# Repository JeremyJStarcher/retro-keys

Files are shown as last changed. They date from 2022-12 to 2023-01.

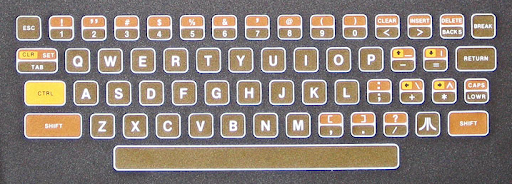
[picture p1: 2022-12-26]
keyboards/atari-a8/img/atari-400-keyboard-layout.png

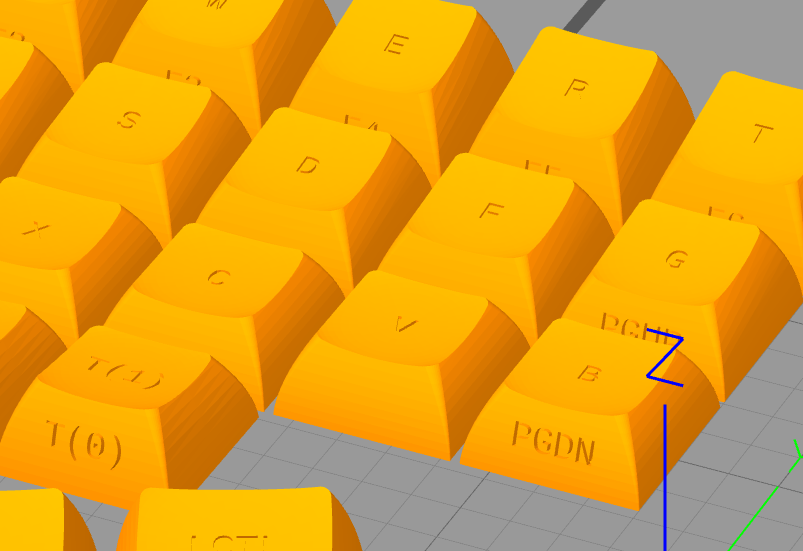
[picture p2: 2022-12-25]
keyboards/openscad/KeyV2/assets/dual_legends.png

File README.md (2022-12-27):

# retro-keys

Retro Keyboards for Emulators

## Purpose

The purpose of this project is to set up a tools to make it easier to create
a custom keyboard to use retro-style computers on modern emulators.

This includes the PCB, keycaps and (in time) a case.

Better integration with [QMK](https://qmk.fm/) is planned.

## Keyboard support

* Atari 800/800XL style keyboard.

## Requirements

* Python 3.10
* OpenSCAD
* KiCad
* VcCode (other editors will work but may require configuration)

## After clone

All of the Python scripts run in a `virtual environment` which will allow them to
access privately installed libraries.

### Step 1 - Install Python `venv`

This package must be installed globally.

    pip install venv

### Step 2 - Create the virtual environment (only needs done once after clone)

In your shell/commandline of choice, change directory to the project root `py`
directory.

    python3 -m venv .venv

### Step 3 - Enter virtual environment (needs done every time you with with `retro-keys`)

From the `py` directory, enter the following command

Linux/Unix:

    source .venv/bin/activate

### Step 4 - Install the required libraries into the virtual environment.

    ./py_libs.sh

## Directory layout

The `keyboards` directory contains the data required for each unique keyboard
as well as common code (and graphics) libraries that are used by all keyboards.

    * `atari-a8` - Keyboard 800/800XL layout
    * `c64-vic20` - C64/VIC20 keyboard (in development)
    * `kicad-lib` - Graphics libraries
    * `openscad` - Open SCAD libraries
    * `retrologo-kb` - Fake keyboard used to generate website graphics.

For each actual keyboard, the directory structure is:

    * `kicad` - The KiCad project for that keyboard
    * `keycaps` - The OpenSCAD scripts to generate the keyboard.

It is important to note that the generated key graphics, stl and wrl files are NOT
checked into the repo as they would take up a large amount of space and must be
regenerated when working on that keyboard.

### Working with an existing keyboard

Yet to be documented.  This workflow is still somewhat reliant on a QMK script
outside the `retro-keys` project directory structure.

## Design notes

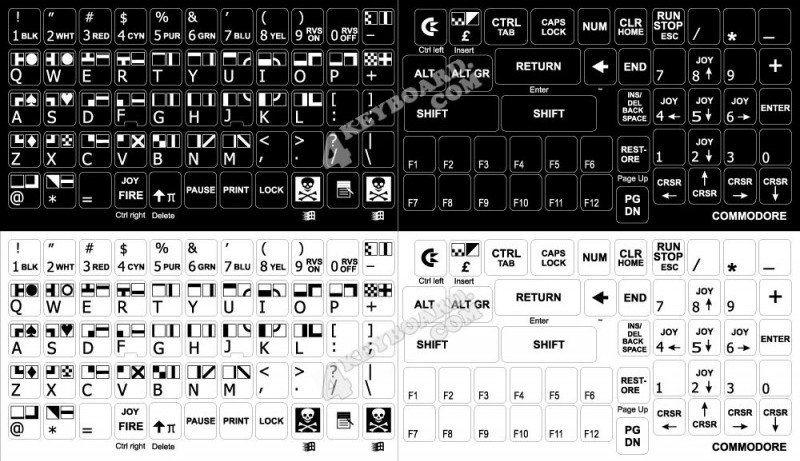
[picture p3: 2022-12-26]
keyboards/c64-vic20/imgs/4kb-c64_stickers.jpg

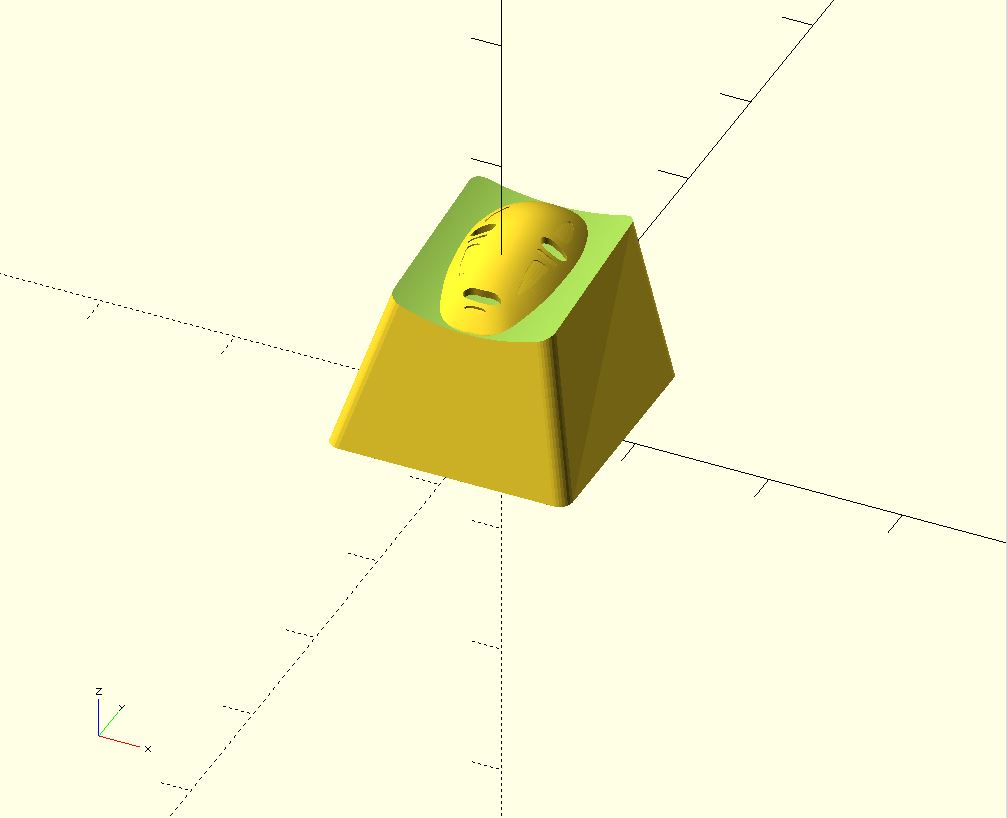
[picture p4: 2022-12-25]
keyboards/openscad/KeyV2/assets/example4.JPG

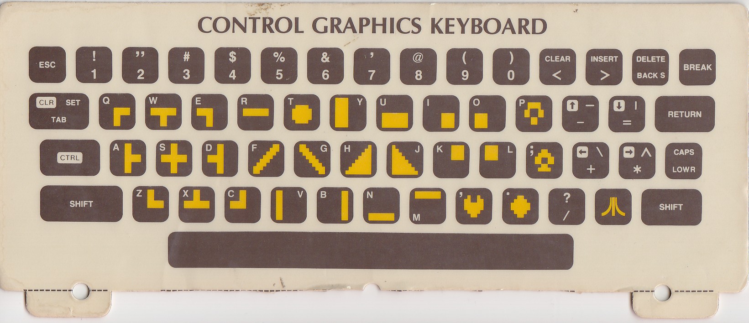
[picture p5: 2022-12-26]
keyboards/atari-a8/img/atari-keyboard-graphics.jpg

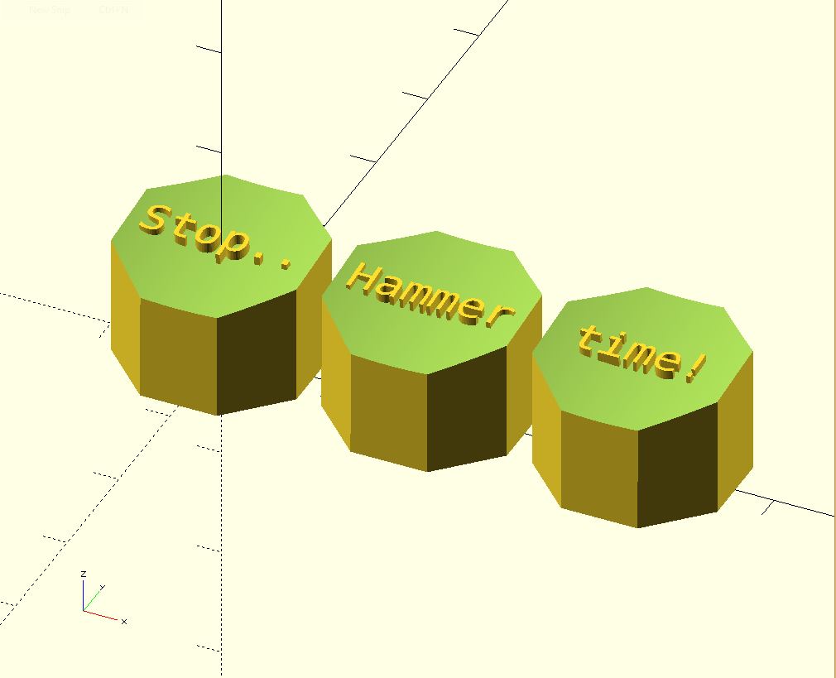
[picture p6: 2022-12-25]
keyboards/openscad/KeyV2/assets/example5.JPG

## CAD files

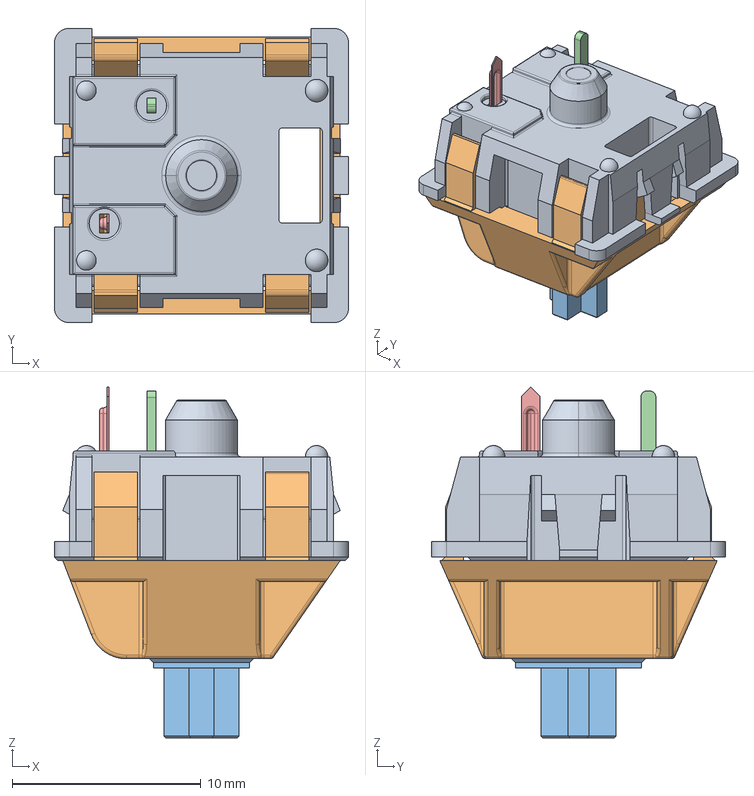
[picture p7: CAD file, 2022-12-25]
keyboards/kicad-lib/3d-models/cherry-mx-switches/asm_mx_asm_PLATE.stp
15.6 x 15.6 x 18.6 mm
MX_DOWN
MX_UP
UP_MX
MX_PIN
MX_SPRING
MX_CLICK

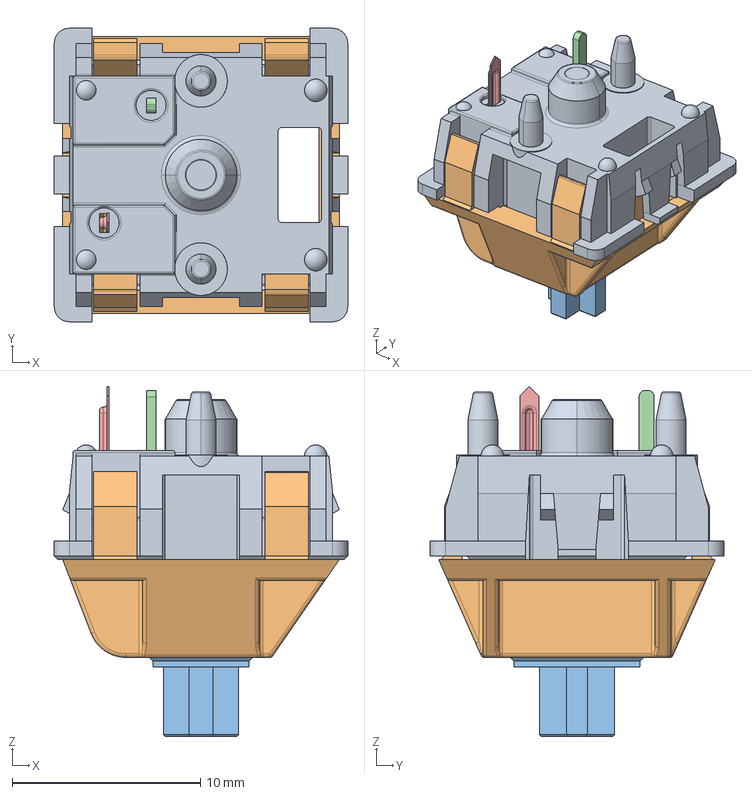
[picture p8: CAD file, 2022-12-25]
keyboards/kicad-lib/3d-models/cherry-mx-switches/asm_mx_asm_PCB.stp
15.6 x 15.6 x 18.6 mm
MX_DOWN
MX_UP
UP_MX
MX_PIN
MX_SPRING
MX_CLICK

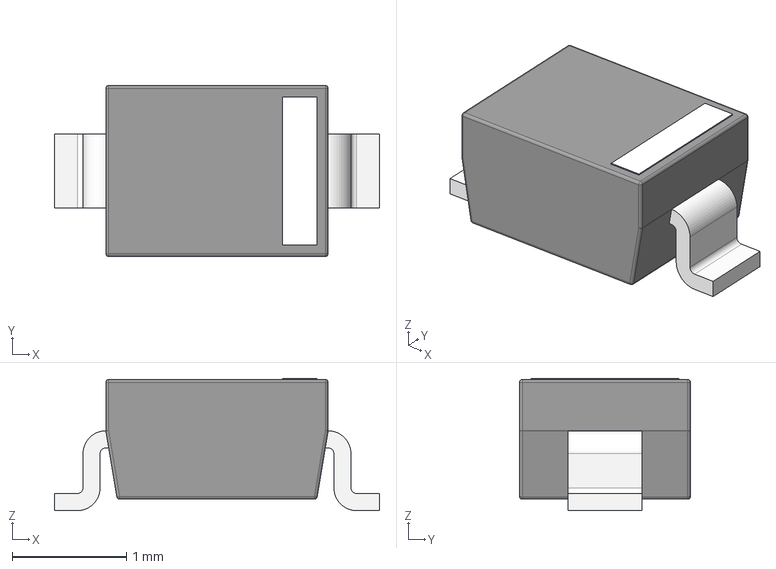
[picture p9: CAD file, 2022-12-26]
keyboards/kicad-lib/3d-models/SOD-diodes/SOD-323.step
2.85 x 1.50 x 1.16 mm

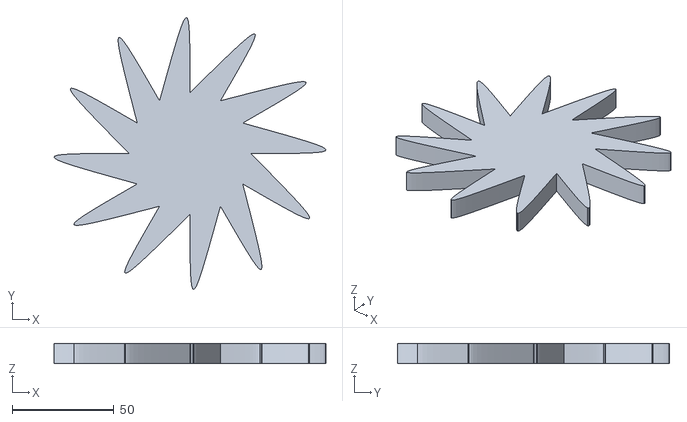
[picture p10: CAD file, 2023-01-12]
keyboards/openscad/josl/josl/bezier/examples/flower.stl
134.0 x 134.0 x 10.0

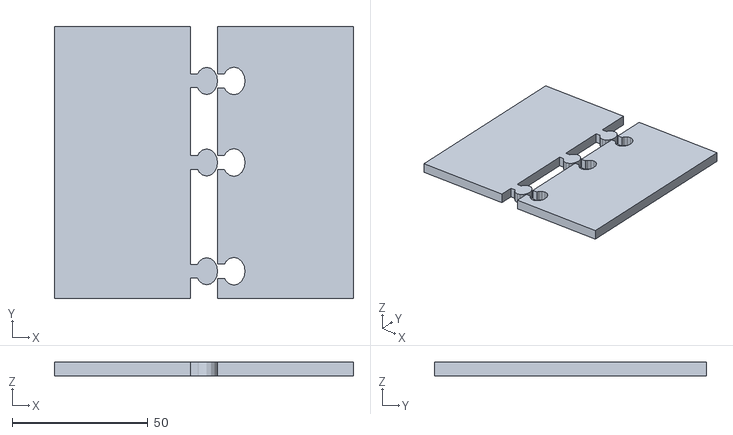
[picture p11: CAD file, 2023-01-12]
keyboards/openscad/josl/josl/cuts/examples/box-example.stl
110.0 x 100.0 x 5.00

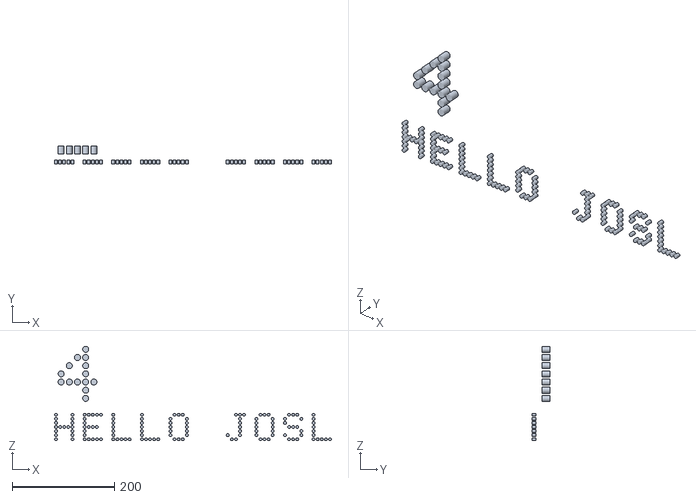
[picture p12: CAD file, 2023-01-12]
keyboards/openscad/josl/josl/dotletter/examples/hello-josl.stl
542.0 x 36.0 x 184.8

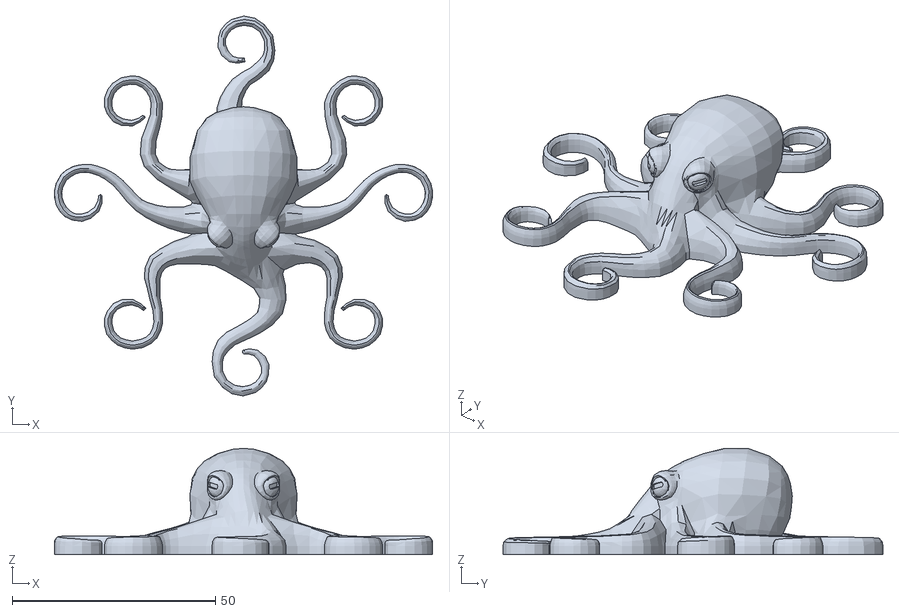
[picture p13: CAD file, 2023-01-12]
keyboards/openscad/puzzlecut/files/OctopusThickLegs.stl
93.0 x 93.4 x 26.1

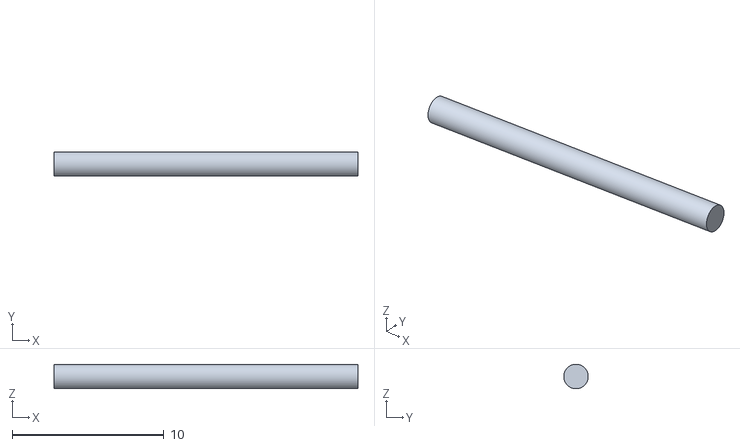
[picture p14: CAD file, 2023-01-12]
keyboards/openscad/test.stl
20.0 x 1.61 x 1.61

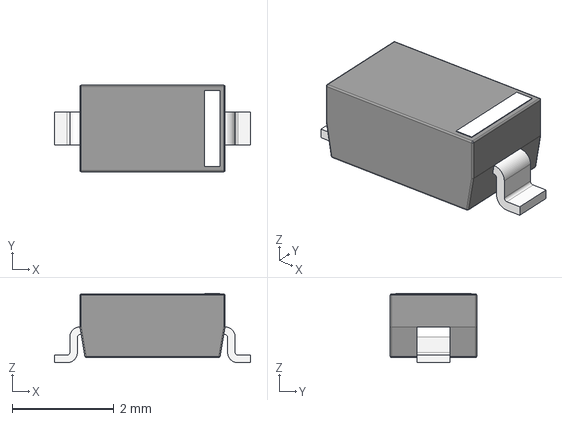
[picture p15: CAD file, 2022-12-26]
keyboards/kicad-lib/3d-models/SOD-diodes/SOD-123.step
3.85 x 1.70 x 1.36 mm

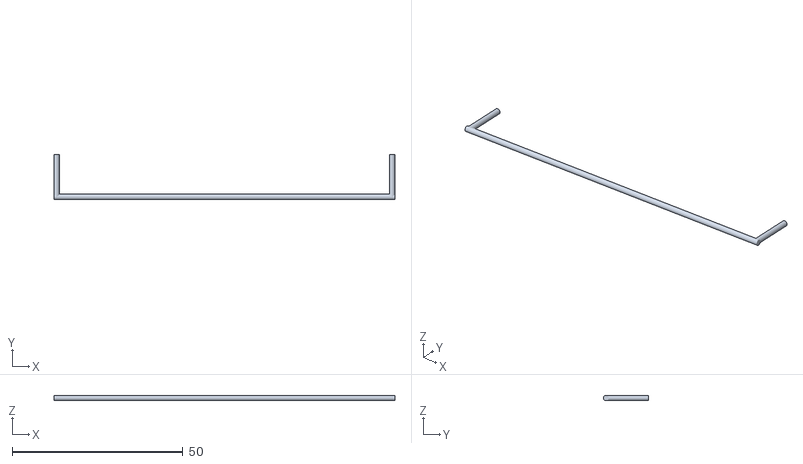
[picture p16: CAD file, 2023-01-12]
keyboards/openscad/625u.stl
100.0 x 13.3 x 1.61

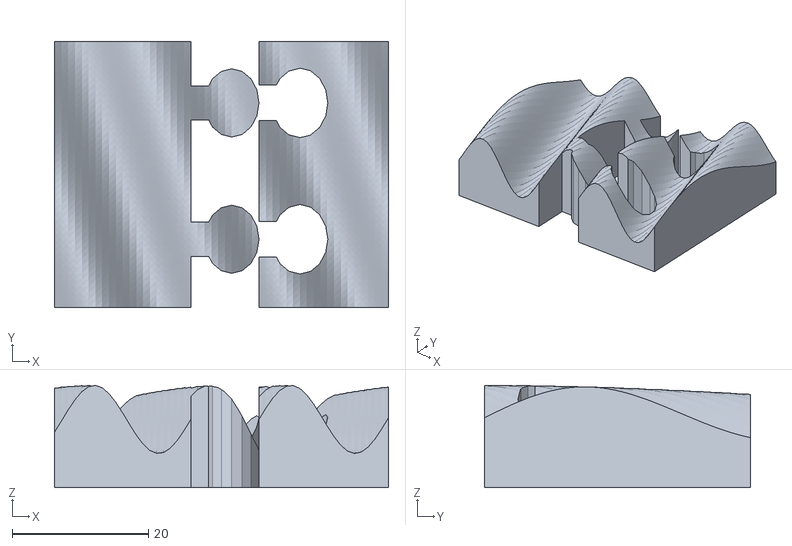
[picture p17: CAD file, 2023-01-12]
keyboards/openscad/josl/josl/cuts/examples/surface-example.stl
49.0 x 39.0 x 15.0

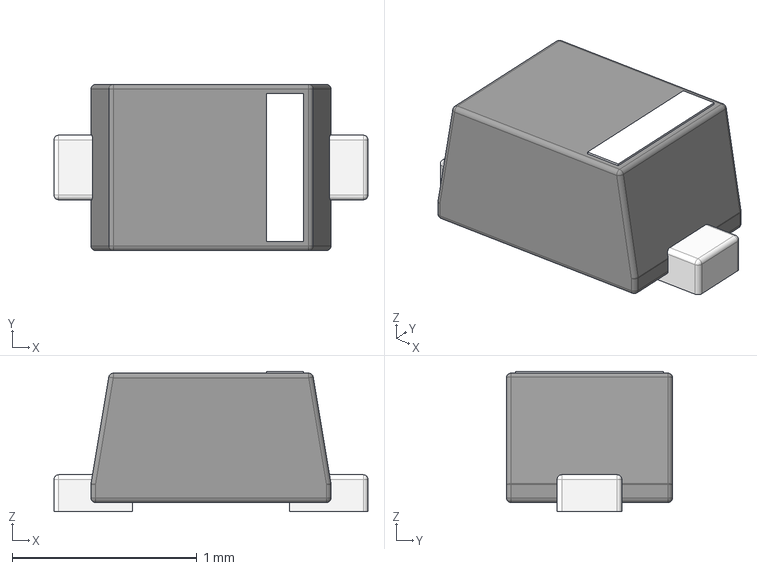
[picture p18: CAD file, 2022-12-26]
keyboards/kicad-lib/3d-models/SOD-diodes/SOD-523.step
1.70 x 0.9 x 0.76 mm

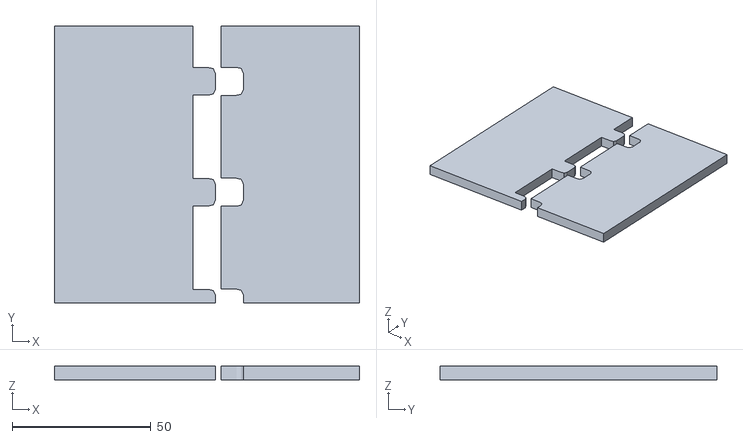
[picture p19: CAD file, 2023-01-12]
keyboards/openscad/josl/josl/cuts/examples/rounded-box-example.stl
110.0 x 100.0 x 5.00

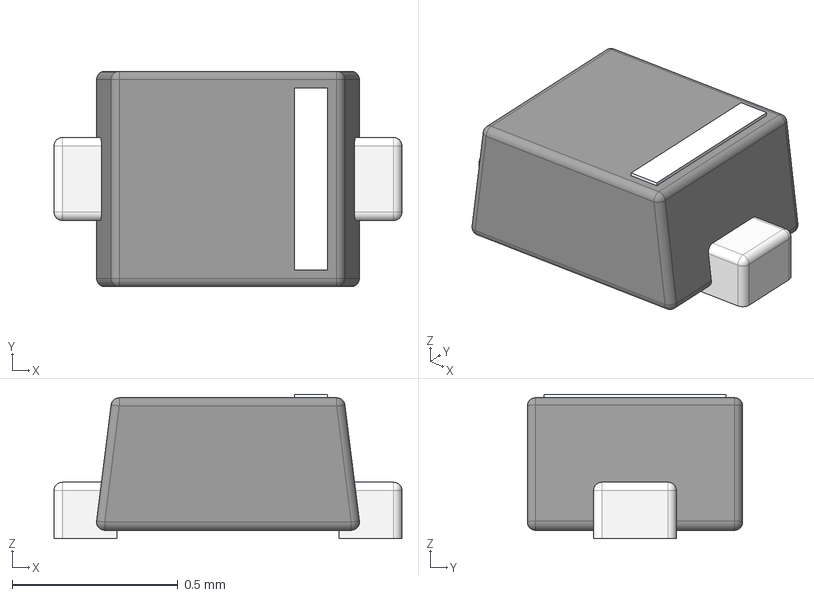
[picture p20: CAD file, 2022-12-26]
keyboards/kicad-lib/3d-models/SOD-diodes/SOD-923 0.2mm Lead Width.step
1.05 x 0.65 x 0.435 mm

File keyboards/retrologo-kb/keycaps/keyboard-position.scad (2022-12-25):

KEY_ESC = [0, 1.5, 63.38125, 206.325];
KEY_1 = [1.25, 1.5, 84.8125, 206.325];
KEY_2 = [2.25, 1.5, 103.86250000000001, 206.325];
KEY_3 = [3.25, 1.5, 122.9125, 206.325];
KEY_4 = [4.25, 1.5, 141.9625, 206.325];
KEY_5 = [5.25, 1.5, 161.0125, 206.325];
KEY_6 = [6.25, 1.5, 180.0625, 206.325];
KEY_7 = [7.25, 1.5, 199.1125, 206.325];
KEY_8 = [8.25, 1.5, 218.1625, 206.325];
KEY_9 = [9.25, 1.5, 237.2125, 206.325];
KEY_0 = [10.25, 1.5, 256.26250000000005, 206.325];
KEY_LT = [11.25, 1.5, 275.3125, 206.325];
KEY_GT = [12.25, 1.5, 294.3625, 206.325];
KEY_BS = [13.25, 1.5, 322.9375, 206.325];
KEY_C_UP = [14.25, 4.5, 332.46250000000003, 263.475];
KEY_C_LEFT = [13.25, 5.5, 313.4125, 282.525];
KEY_C_DOWN = [14.25, 5.5, 332.46250000000003, 282.525];
KEY_C_RIGHT = [15.25, 5.5, 351.5125, 282.525];
KEY_TAB = [0, 2.5, 68.14375, 225.375];
KEY_Q = [1.75, 2.5, 94.3375, 225.375];
KEY_W = [2.75, 2.5, 113.3875, 225.375];
KEY_E = [3.75, 2.5, 132.4375, 225.375];
KEY_R = [4.75, 2.5, 151.4875, 225.375];
KEY_T = [5.75, 2.5, 170.53750000000002, 225.375];
KEY_Y = [6.75, 2.5, 189.5875, 225.375];
KEY_U = [7.75, 2.5, 208.63750000000002, 225.375];
KEY_I = [8.75, 2.5, 227.6875, 225.375];
KEY_O = [9.75, 2.5, 246.7375, 225.375];
KEY_P = [10.75, 2.5, 265.7875, 225.375];
KEY_DASH = [11.75, 2.5, 284.8375, 225.375];
KEY_EQUAL = [12.75, 2.5, 303.88750000000005, 225.375];
KEY_RETURN = [13.75, 2.5, 327.7, 225.375];
KEY_HELP = [16.5, 0, 377.70625, 180.13125];
KEY_RESET = [16.5, 1.5, 377.70625, 208.70624999999998];
KEY_OPTION = [16.5, 2.75, 377.70625, 232.51874999999998];
KEY_SELECT = [16.5, 4, 377.70625, 256.33125];
KEY_CONTROL = [0, 3.5, 70.525, 244.425];
KEY_A = [2, 3.5, 99.1, 244.425];
KEY_S = [3, 3.5, 118.15, 244.425];
KEY_D = [4, 3.5, 137.2, 244.425];
KEY_F = [5, 3.5, 156.25, 244.425];
KEY_G = [6, 3.5, 175.3, 244.425];
KEY_H = [7, 3.5, 194.35, 244.425];
KEY_J = [8, 3.5, 213.4, 244.425];
KEY_K = [9, 3.5, 232.45000000000002, 244.425];
KEY_L = [10, 3.5, 251.5, 244.425];
KEY_SEMI = [11, 3.5, 270.55, 244.425];
KEY_PLUS = [12, 3.5, 289.6, 244.425];
KEY_ASTRIX = [13, 3.5, 308.65, 244.425];
KEY_CAPS = [14, 3.5, 330.08125, 244.425];
KEY_START = [16.5, 5.25, 377.70625, 280.14375];
KEY_POWER = [3.25, 0, 125.29374999999999, 180.13125];
KEY_MENU = [5.25, 0, 163.39374999999998, 180.13125];
KEY_TURBO = [6.5, 0, 187.20624999999998, 180.13125];
KEY_FN = [2, 5.5, 99.1, 282.525];
KEY_LSHIFT = [0.25, 4.5, 77.66875, 263.475];
KEY_Z = [2.5, 4.5, 108.625, 263.475];
KEY_X = [3.5, 4.5, 127.675, 263.475];
KEY_C = [4.5, 4.5, 146.72500000000002, 263.475];
KEY_V = [5.5, 4.5, 165.775, 263.475];
KEY_B = [6.5, 4.5, 184.825, 263.475];
KEY_N = [7.5, 4.5, 203.875, 263.475];
KEY_M = [8.5, 4.5, 222.925, 263.475];
KEY_COMMA = [9.5, 4.5, 241.975, 263.475];
KEY_PERIOD = [10.5, 4.5, 261.025, 263.475];
KEY_SLASH = [11.5, 4.5, 280.07500000000005, 263.475];
KEY_RSHIFT = [12.5, 4.5, 306.26875, 263.475];
KEY_INV = [12.75, 0, 306.26875000000007, 180.13125];
KEY_BREAK = [14, 0, 330.08125, 180.13125];
KEY_SPACE = [4.75, 5.5, 201.49375, 282.525];

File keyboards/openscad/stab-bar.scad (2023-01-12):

len = 20; // 100;
deep = 12.5;
d = 1.61; // 1/16"
turn_radius = 2;

$fn = 100;

module outline() {
    module e() {
        translate([len/2 - d/2, deep/2, 0])
        rotate([90, 0, 0])
        cylinder(h = deep, r = d/2, center=true);
    }


     translate([0, 0, 0]) {
        rotate([0, 90, 0])
        cylinder(h = len, r = d/2, center=true);


        
        // e();
        // mirror([1, 0, 0]) e();
    }
}


outline();



module side() {

    
    translate([len/2 - turn_radius, turn_radius/2, 0])

    rotate([0, 0, 90 * 3])
    rotate_extrude( angle=90)
    translate([turn_radius/2,0,0])
    circle(r = d/4);
    
    
    color("blue")
    translate([len/2 - d/2, deep, 0])
    rotate([90, 0, 0])
    cylinder(h = deep - turn_radius/2, r = d/2);
    
}

//rotate([0, 90, 0])
//cylinder(h = len - turn_radius, r = d/2, center=true);

//side();
///mirror([1, 0, 0]) side();

//square([2,10], center=true);

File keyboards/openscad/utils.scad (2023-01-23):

use <./josl/josl/cuts/comb.scad>
use <./josl/josl/cuts/leftright.scad>
use <./josl/josl/cuts/puzzle.scad>
use <./josl/josl/cuts/zigzag.scad>

module main(BOARD_WIDTH, BOARD_LEN, CASE_PIECES, CASE_PIECE)
{
    $fs = 0.5;
    $fa = 5;

    // Radius of the case corner
    CASE_CORNER_R = 3;
    PCB_THICKNESS = 1.6;
    SCREW_HEAD_GAP = 3;
    SCREW_HEAD_R = 3;
    LAYER_HEIGHT = 0.2;

    // HOw much of a gap between the PCB and the case
    CASE_GAP = 2;

    function puzzleApart() = max(BOARD_WIDTH, BOARD_LEN);

    module centerChildren()
    {
        translate([ BOARD_X1, BOARD_Y1, 0 ]) children();
    }

    module tube(or, ir, h)
    {
        difference()
        {
            cylinder(h = h, r = or);
            translate([ 0, 0, -h / 2 ]) cylinder(h = h * 2, r = ir);
        }
    }

    module mirror4()
    {
        children();
        mirror([ 1, 0, 0 ]) children();
        mirror([ 0, 1, 0 ]) children();
        mirror([ 0, 1, 0 ]) mirror([ 1, 0, 0 ]) children();
    }

    module bottomCase(blen2, bwidth2, offset, height)
    {
        blen = blen2 + offset * 2;
        bwidth = bwidth2 + offset * 2;

        hull() mirror4()
        {
            translate([ -blen / 2, -bwidth / 2, 0 ]) cylinder(h = height, r = CASE_CORNER_R);
        }
    }

    module mountingHoles(blen, bwidth, offset, height)
    {
        mirror4()                                                      //
            translate([ -blen / 2 + offset, -bwidth / 2 + offset, 0 ]) //
            cylinder(h = height * 10, r = MOUNTING_HOLE_D / 2);

        // Drop down below the zero line to make sure there is no interference
        mirror4() //
            translate([ -blen / 2 + offset, -bwidth / 2 + offset, -SCREW_HEAD_GAP ])
        { //
            cylinder(h = SCREW_HEAD_GAP * 2, r = SCREW_HEAD_R + 1);
            //  cylinder(h = SCREW_HEAD_GAP *2, r2 = SCREW_HEAD_R+1, r1=MOUNTING_HOLE_D / 2);
        }
    }

    module mountingStandoffs(blen, bwidth, offset, d, height)
    {
        // The real radius gets put in during voids
        color("red") mirror4() translate([ -blen / 2 + offset, -bwidth / 2 + offset, 0 ]) tube(d + 2, .1, height);
    }

    module bodyVoids()
    {
        mountingHoles(BOARD_LEN, BOARD_WIDTH, MOUNTING_HOLE_OFFSET, STANDOFF_HOLE_HEIGHT);
    }

    module line(x1, y1, x2, y2)
    {
        hull()
        {
            translate([
                x1,
                y1,
            ]) cube(2);
            translate([
                x2,
                y2,
            ]) cube(2);
        }
    }

    module standOffs()
    {

        $fa = 1;
        $fs = 1;

        for (standoff = keyStandoffs)
        {
            x = standoff[0];
            y = standoff[1];

            color("black") translate([ x, y, 0 ])
            {
                cylinder(r = STANDOFF_HOLE_OUTER_DIAMETER / 2, h = STANDOFF_HOLE_HEIGHT);
                cylinder(r1 = STANDOFF_HOLE_INNER_DIAMETER / 2, r2 = (STANDOFF_HOLE_INNER_DIAMETER / 2) * .9,
                         h = STANDOFF_HOLE_HEIGHT + PCB_THICKNESS);
            }
        }
    }

    module keyBoundingBoxes()
    {
        for (box = keyBoundingBoxes)
        {
            x1 = box[1];
            y1 = box[2];
            x2 = box[3];
            y2 = box[4];

            translate([ 0, 0, 0 ]) color("blue")
            {
                line(x1, y1, x2, y1);
                line(x1, y2, x2, y2);
                line(x1, y1, x1, y2);
                line(x2, y1, x2, y2);
            }

            cx = (x1 + x2) / 2;
            cy = (y1 + y2) / 2;

            // Grab just the first two characters since the whole name won't fit
            // in a readable font
            char1 = is_string(box[0][0]) ? box[0][0] : "";
            char2 = is_string(box[0][1]) ? box[0][1] : "";
            label = str(char1, char2);

            color("green") translate(v = [ cx, cy, 0 ]) linear_extrude(height = LAYER_HEIGHT)
                text(label, valign = "center", halign = "center", size = 9);
        }
    }

    module centerCubeXy(wid, len, height)
    {
        translate([ -wid / 2, -len / 2, BASE_THICKNESS ]) cube([ wid, len, height ]);
    }

    module body()
    {
        outside_len = BOARD_LEN + CASE_CORNER_R + CASE_GAP;
        outside_width = BOARD_WIDTH + CASE_CORNER_R + CASE_GAP;

        lip_len = outside_len - (CASE_CORNER_R);
        lip_width = outside_width - (CASE_CORNER_R);

        difference()
        {
            union()
            {
                color("cyan") bottomCase(outside_len, outside_width, 0, CASE_HEIGHT);
                translate([ 0, 0, BASE_THICKNESS ]) color("green")
                    bottomCase(lip_len, lip_width, 0, CASE_HEIGHT + 5 - BASE_THICKNESS);
            }

            translate([ 0, 0, -BASE_THICKNESS ])
                centerCubeXy(BOARD_LEN + CASE_GAP, BOARD_WIDTH + CASE_GAP, CASE_HEIGHT * 3);
        }

        // Put the bottom of the case in.
        translate([ 0, 0, 0 ]) //
            color("white")     //
            bottomCase(outside_len, outside_width, 0, BASE_THICKNESS);

        translate([ 0, 0, BASE_THICKNESS ]) centerChildren()
        {
            standOffs();
            keyBoundingBoxes();
        }
        translate([ 0, 0, BASE_THICKNESS ])
            mountingStandoffs(BOARD_LEN, BOARD_WIDTH, MOUNTING_HOLE_OFFSET, MOUNTING_HOLE_D, STANDOFF_HOLE_HEIGHT);
    }

    module keyboardCaseBottom()
    {
        difference()
        {
            body();
            bodyVoids();
        }
    }

    module hideyCube(side, len, width)
    {
        ap = puzzleApart();
        cube([ ap, ap, 100 ], center = true);
    }

    module cutIt(side, len, width)
    {
        $CUT_WIDTH = width;
        ap = puzzleApart();

        factor = 4;

        xOffset = +len / factor + ap / 2;
        xOffsetFixed = xOffset * (side == "r" ? 1 : -1);

        intersection()
        {
            translate([ xOffsetFixed, 0, 0 ]) children();
            hideyCube(side, len, width);
        }
    }

    module split()
    {
        slice = 25;
        list1 = [for (i = [-$CUT_WIDTH:slice:$CUT_WIDTH]) i];
        play = 0.1;

        Puzzle(y = list1, apart = puzzleApart(), play = play)
        {
            children();
        }
    }

    function partial(list, start, end) = [for (i = [start:end]) list[i]];

    module main2()
    {
        // keyboardCaseBottom();

        module cutInto4(c1, c2)
        {
            cutIt(c2, BOARD_LEN / 2, BOARD_WIDTH) //
                split()                           //
                cutIt(c1, BOARD_LEN, BOARD_WIDTH) //
                split()                           //
                keyboardCaseBottom();
        }

        module cutInto2(c1)
        {
            cutIt(c1, BOARD_LEN, BOARD_WIDTH) //
                split()                       //
                keyboardCaseBottom();
        }

        if (CASE_PIECES == 2)
        {
            if (CASE_PIECE == 1)
            {
                cutInto2("l");
            }
            if (CASE_PIECE == 2)
            {
                cutInto2("r");
            }
        }

        if (CASE_PIECES == 4)
        {
            if (CASE_PIECE == 1)
            {
                cutInto4("l", "l");
            }

            if (CASE_PIECE == 2)
            {
                cutInto4("l", "r");
            }

            if (CASE_PIECE == 3)
            {
                cutInto4("r", "l");
            }

            if (CASE_PIECE == 4)
            {
                cutInto4("r", "r");
            }
        }
    }

    main2();

    lst = [ 1, 2, 3, 4, 5, 6, 7, 8, 9 ]; // a list of numbers
    lst2 = [ "red", "yellow", "blue" ];  // a list of strings
    lst3 = [ false, true, undef ];       // a list of booleans

    // https://eribuijs.blogspot.com/2017/10/openscad-lists-and-list-manipulation.html

    // echo(partial(lst, 1, 8));
}

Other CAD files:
keyboards/kicad-lib/3d-models/SOD-diodes/SOD-923 0.3mm Lead Width.step
keyboards/atari-a8/case/case-position.scad
keyboards/atari-a8/keycaps/atarikeys.scad
keyboards/atari-a8/keycaps/key_desc.scad
keyboards/atari-a8/keycaps/key_include.scad
keyboards/atari-a8/keycaps/one_atari_key.scad
keyboards/openscad/KeyV2/customizer.scad
keyboards/openscad/KeyV2/customizer_base.scad
keyboards/openscad/KeyV2/examples/legends.scad
keyboards/openscad/KeyV2/examples/multimaterial_key_top.scad
keyboards/openscad/KeyV2/examples/multimaterial_legend.scad
keyboards/openscad/KeyV2/examples/plate_generation.scad
keyboards/openscad/KeyV2/examples/print_keycaps_on_their_side.scad
keyboards/openscad/KeyV2/examples/sa_ergo.scad
keyboards/openscad/KeyV2/examples/single_extruder_multimaterial_legends.scad
keyboards/openscad/KeyV2/includes.scad
keyboards/openscad/KeyV2/key_mold.scad
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

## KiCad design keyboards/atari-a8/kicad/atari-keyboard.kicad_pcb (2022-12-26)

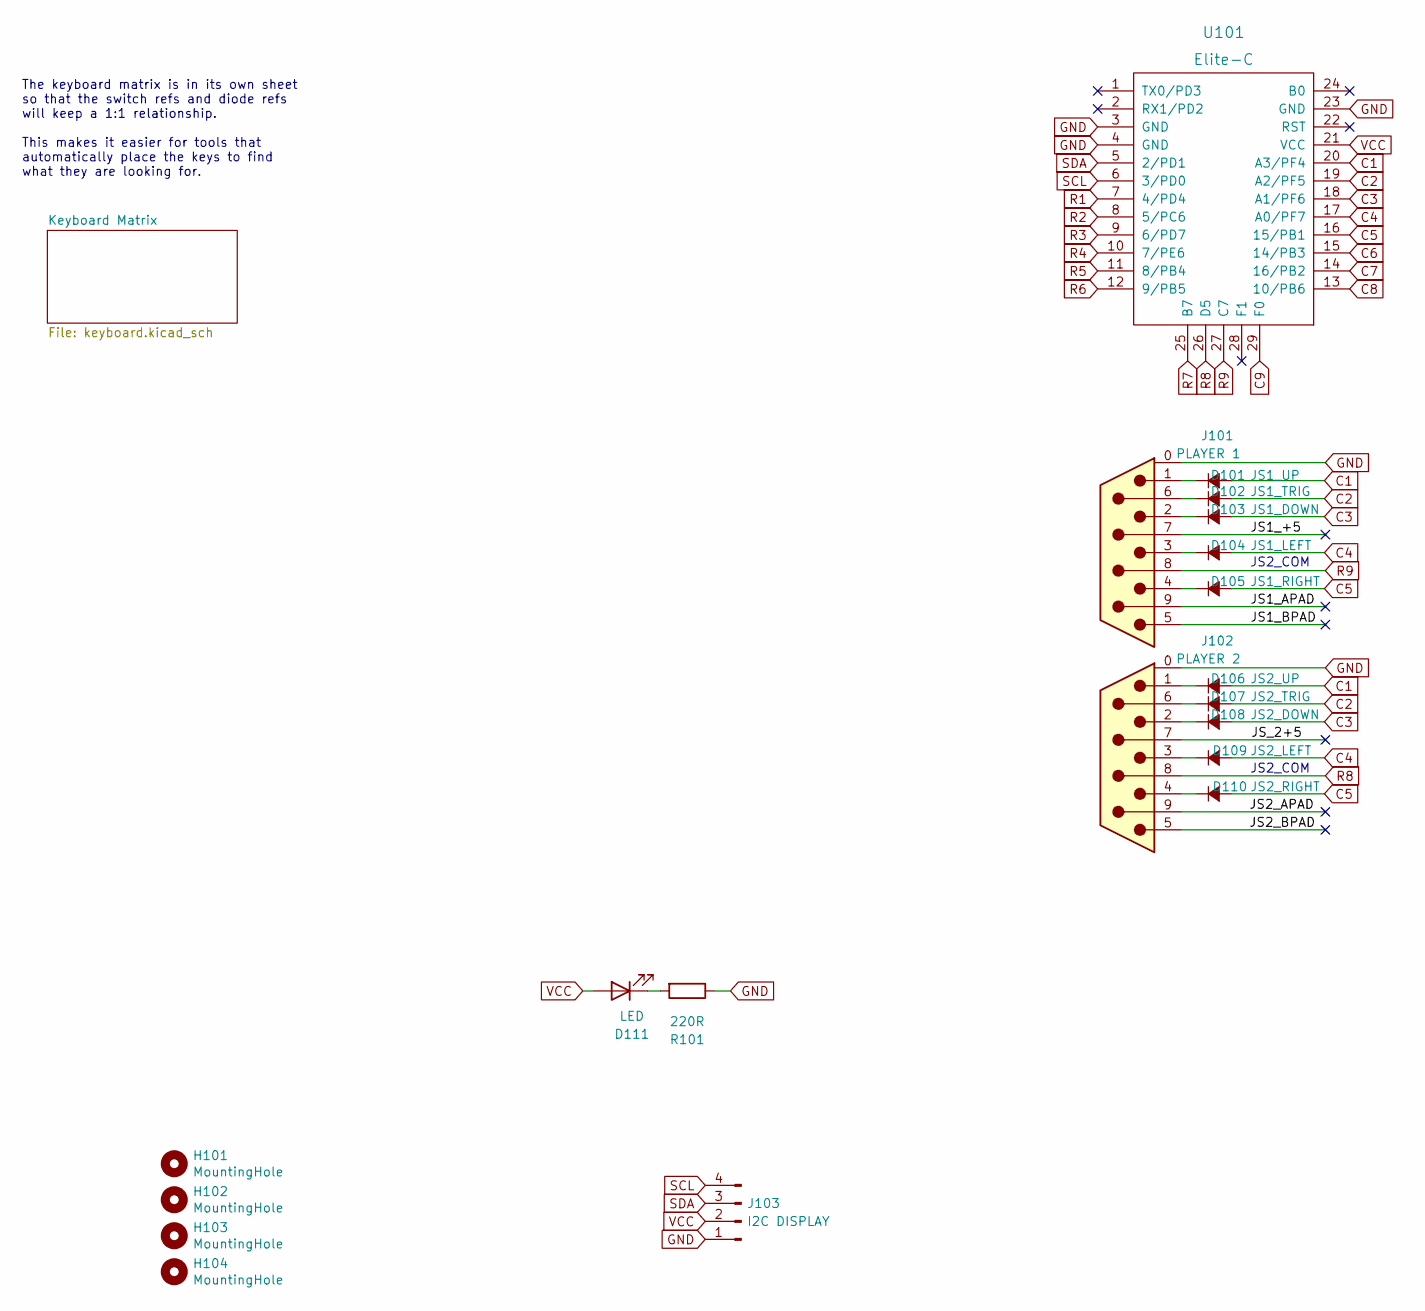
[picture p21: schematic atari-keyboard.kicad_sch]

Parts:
D101: JS1_UP; Diode-dual
D102: JS1_TRIG; Diode-dual
D103: JS1_DOWN; Diode-dual
D104: JS1_LEFT; Diode-dual
D105: JS1_RIGHT; Diode-dual
D106: JS2_UP; Diode-dual
D107: JS2_TRIG; Diode-dual
D108: JS2_DOWN; Diode-dual
D109: JS2_LEFT; Diode-dual
D110: JS2_RIGHT; Diode-dual
D111: LED; LED_D3.0mm
H101, H102, H103, H104: MountingHole; MountingHole_3.2mm_M3
J101: PLAYER 1; DSUB-9_Male_Horizontal_P2.77x2.84mm_EdgePinOffset9.90mm_Hou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
J102: PLAYER 2; DSUB-9_Male_Horizontal_P2.77x2.84mm_EdgePinOffset9.90mm_Hou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
J103: I2C DISPLAY; PinHeader_1x04_P2.54mm_Horizontal
R101: 220R; Resistor-Hybrid
U101: Elite-C; Elite-C-castellated-29pin-holes

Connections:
/JS1_+5: J101.7
/JS1_APAD: J101.9
/JS1_BPAD: J101.5
/JS2_APAD: J102.9
/JS2_BPAD: J102.5
/JS_2+5: J102.7
C1: D101.2 (A), D106.2 (A), U101.20 (A3/PF4); also elsewhere on the board
C2: D102.2 (A), D107.2 (A), U101.19 (A2/PF5); also elsewhere on the board
C3: D103.2 (A), D108.2 (A), U101.18 (A1/PF6); also elsewhere on the board
C4: D104.2 (A), D109.2 (A), U101.17 (A0/PF7); also elsewhere on the board
C5: D105.2 (A), D110.2 (A), U101.16 (15/PB1); also elsewhere on the board
C6: U101.15 (14/PB3); also elsewhere on the board
C7: U101.14 (16/PB2); also elsewhere on the board
C8: U101.13 (10/PB6); also elsewhere on the board
C9: U101.29 (F0); also elsewhere on the board
GND: J101.0 (GND), J102.0 (GND), J103.1, R101.1, U101.3 (GND), U101.4 (GND), U101.23 (GND)
unnamed: D101.1 (K), J101.1
unnamed: D102.1 (K), J101.6
unnamed: D103.1 (K), J101.2
unnamed: D104.1 (K), J101.3
unnamed: D105.1 (K), J101.4
unnamed: D106.1 (K), J102.1
unnamed: D107.1 (K), J102.6
unnamed: D108.1 (K), J102.2
unnamed: D109.1 (K), J102.3
unnamed: D110.1 (K), J102.4
unnamed: D111.1 (K), R101.2
R1: U101.7 (4/PD4); also elsewhere on the board
R2: U101.8 (5/PC6); also elsewhere on the board
R3: U101.9 (6/PD7); also elsewhere on the board
R4: U101.10 (7/PE6); also elsewhere on the board
R5: U101.11 (8/PB4); also elsewhere on the board
R6: U101.12 (9/PB5); also elsewhere on the board
R7: U101.25 (B7); also elsewhere on the board
R8: J102.8, U101.26 (D5); also elsewhere on the board
R9: J101.8, U101.27 (C7); also elsewhere on the board
SCL: J103.4, U101.6 (3/PD0)
SDA: J103.3, U101.5 (2/PD1)
VCC: D111.2 (A), J103.2, U101.21 (VCC)

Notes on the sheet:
JS2_COM
The keyboard matrix is in its own sheet so that the switch refs and diode refs will keep a 1:1 relationship. This makes it easier for tools that automatically place the keys to find what they are looking for.

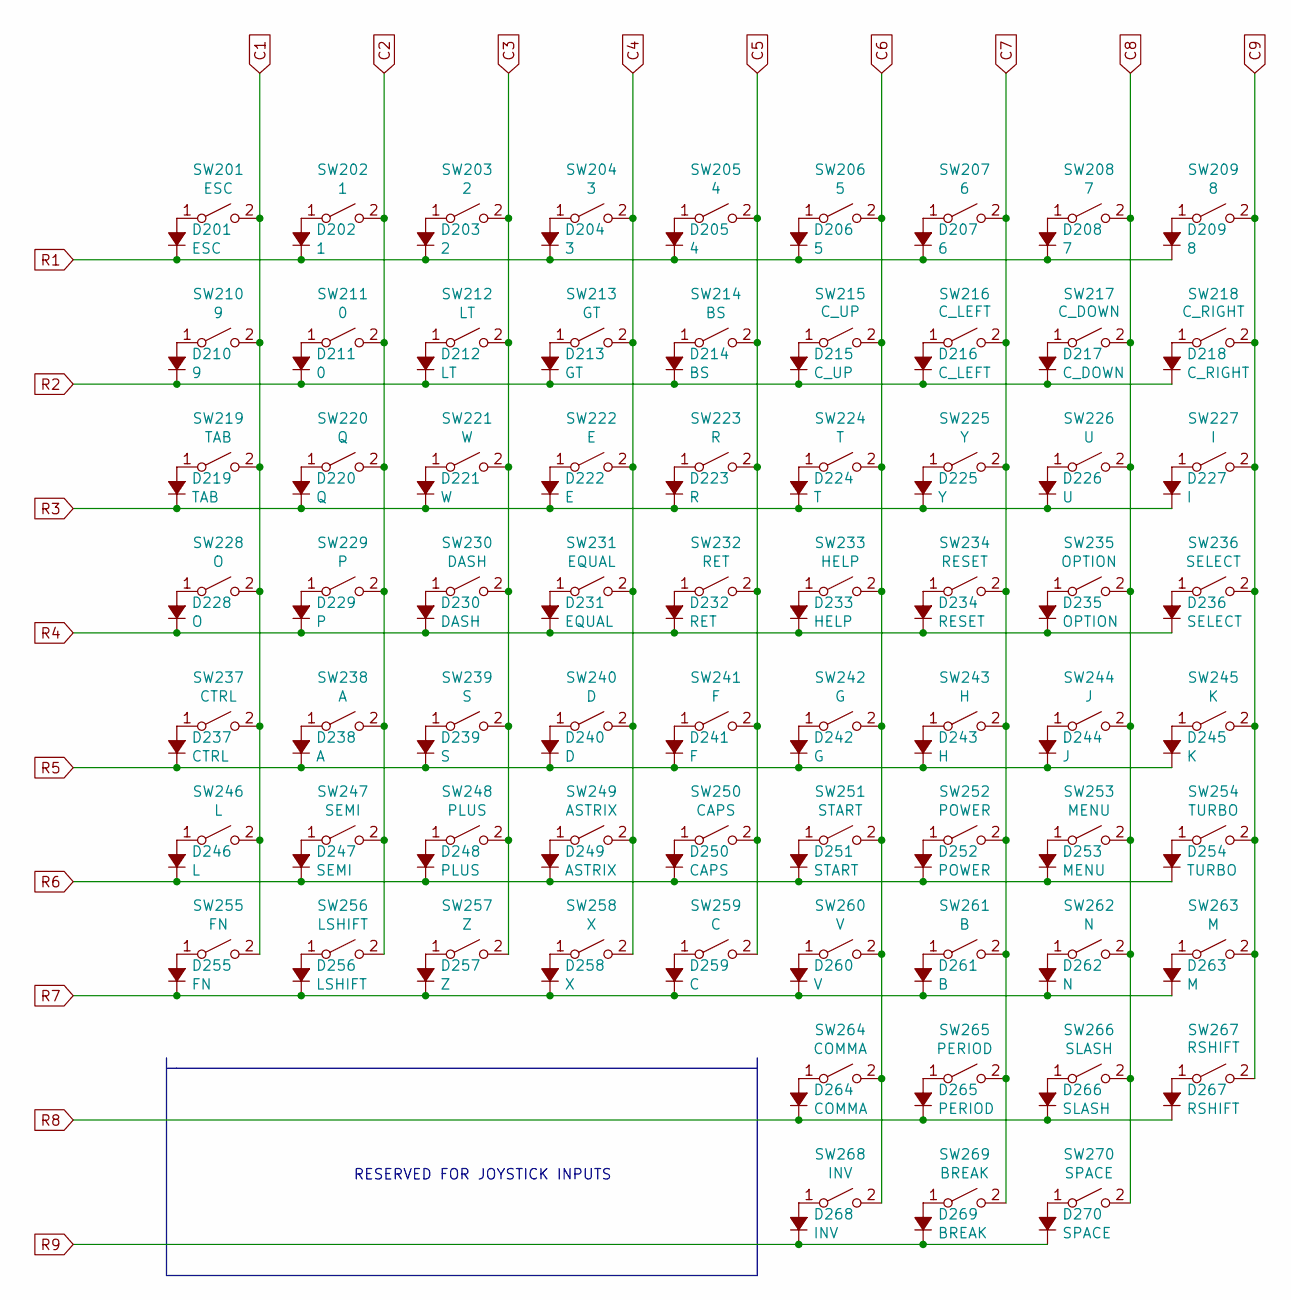
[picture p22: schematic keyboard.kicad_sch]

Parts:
D201: ESC; Diode-dual
D202: 1; Diode-dual
D203: 2; Diode-dual
D204: 3; Diode-dual
D205: 4; Diode-dual
D206: 5; Diode-dual
D207: 6; Diode-dual
D208: 7; Diode-dual
D209: 8; Diode-dual
D210: 9; Diode-dual
D211: 0; Diode-dual
D212: LT; Diode-dual
D213: GT; Diode-dual
D214: BS; Diode-dual
D215: C_UP; Diode-dual
D216: C_LEFT; Diode-dual
D217: C_DOWN; Diode-dual
D218: C_RIGHT; Diode-dual
D219: TAB; Diode-dual
D220: Q; Diode-dual
D221: W; Diode-dual
D222: E; Diode-dual
D223: R; Diode-dual
D224: T; Diode-dual
D225: Y; Diode-dual
D226: U; Diode-dual
D227: I; Diode-dual
D228: O; Diode-dual
D229: P; Diode-dual
D230: DASH; Diode-dual
D231: EQUAL; Diode-dual
D232: RET; Diode-dual
D233: HELP; Diode-dual
D234: RESET; Diode-dual
D235: OPTION; Diode-dual
D236: SELECT; Diode-dual
D237: CTRL; Diode-dual
D238: A; Diode-dual
D239: S; Diode-dual
D240: D; Diode-dual
D241: F; Diode-dual
D242: G; Diode-dual
D243: H; Diode-dual
D244: J; Diode-dual
D245: K; Diode-dual
D246: L; Diode-dual
D247: SEMI; Diode-dual
D248: PLUS; Diode-dual
D249: ASTRIX; Diode-dual
D250: CAPS; Diode-dual
D251: START; Diode-dual
D252: POWER; Diode-dual
D253: MENU; Diode-dual
D254: TURBO; Diode-dual
D255: FN; Diode-dual
D256: LSHIFT; Diode-dual
D257: Z; Diode-dual
D258: X; Diode-dual
D259: C; Diode-dual
D260: V; Diode-dual
D261: B; Diode-dual
D262: N; Diode-dual
D263: M; Diode-dual
D264: COMMA; Diode-dual
D265: PERIOD; Diode-dual
D266: SLASH; Diode-dual
D267: RSHIFT; Diode-dual
D268: INV; Diode-dual
D269: BREAK; Diode-dual
D270: SPACE; Diode-dual
SW201: ESC; SW_Cherry_MX_1.25u_PCB
SW202: 1; SW_Cherry_MX_1.00u_PCB
SW203: 2; SW_Cherry_MX_1.00u_PCB
SW204: 3; SW_Cherry_MX_1.00u_PCB
SW205: 4; SW_Cherry_MX_1.00u_PCB
SW206: 5; SW_Cherry_MX_1.00u_PCB
SW207: 6; SW_Cherry_MX_1.00u_PCB
SW208: 7; SW_Cherry_MX_1.00u_PCB
SW209: 8; SW_Cherry_MX_1.00u_PCB
SW210: 9; SW_Cherry_MX_1.00u_PCB
SW211: 0; SW_Cherry_MX_1.00u_PCB
SW212: LT; SW_Cherry_MX_1.00u_PCB
SW213: GT; SW_Cherry_MX_1.00u_PCB
SW214: BS; SW_Cherry_MX_2.00u_PCB
SW215: C_UP; SW_Cherry_MX_1.00u_PCB
SW216: C_LEFT; SW_Cherry_MX_1.00u_PCB
SW217: C_DOWN; SW_Cherry_MX_1.00u_PCB
SW218: C_RIGHT; SW_Cherry_MX_1.00u_PCB
SW219: TAB; SW_Cherry_MX_1.75u_PCB
SW220: Q; SW_Cherry_MX_1.00u_PCB
SW221: W; SW_Cherry_MX_1.00u_PCB
SW222: E; SW_Cherry_MX_1.00u_PCB
SW223: R; SW_Cherry_MX_1.00u_PCB
SW224: T; SW_Cherry_MX_1.00u_PCB
SW225: Y; SW_Cherry_MX_1.00u_PCB
SW226: U; SW_Cherry_MX_1.00u_PCB
SW227: I; SW_Cherry_MX_1.00u_PCB
SW228: O; SW_Cherry_MX_1.00u_PCB
SW229: P; SW_Cherry_MX_1.00u_PCB
SW230: DASH; SW_Cherry_MX_1.00u_PCB
SW231: EQUAL; SW_Cherry_MX_1.00u_PCB
SW232: RET; SW_Cherry_MX_1.50u_PCB
SW233: HELP; SW_Cherry_MX_1.00u_PCB
SW234: RESET; SW_Cherry_MX_1.00u_PCB
SW235: OPTION; SW_Cherry_MX_1.00u_PCB
SW236: SELECT; SW_Cherry_MX_1.00u_PCB
SW237: CTRL; SW_Cherry_MX_2.00u_PCB
SW238: A; SW_Cherry_MX_1.00u_PCB
SW239: S; SW_Cherry_MX_1.00u_PCB
SW240: D; SW_Cherry_MX_1.00u_PCB
SW241: F; SW_Cherry_MX_1.00u_PCB
SW242: G; SW_Cherry_MX_1.00u_PCB
SW243: H; SW_Cherry_MX_1.00u_PCB
SW244: J; SW_Cherry_MX_1.00u_PCB
SW245: K; SW_Cherry_MX_1.00u_PCB
SW246: L; SW_Cherry_MX_1.00u_PCB
SW247: SEMI; SW_Cherry_MX_1.00u_PCB
SW248: PLUS; SW_Cherry_MX_1.00u_PCB
SW249: ASTRIX; SW_Cherry_MX_1.00u_PCB
SW250: CAPS; SW_Cherry_MX_1.25u_PCB
SW251: START; SW_Cherry_MX_1.00u_PCB
SW252: POWER; SW_Cherry_MX_1.00u_PCB
SW253: MENU; SW_Cherry_MX_1.00u_PCB
SW254: TURBO; SW_Cherry_MX_1.00u_PCB
SW255: FN; SW_Cherry_MX_1.75u_PCB
SW256: LSHIFT; SW_Cherry_MX_2.25u_PCB
SW257: Z; SW_Cherry_MX_1.00u_PCB
SW258: X; SW_Cherry_MX_1.00u_PCB
SW259: C; SW_Cherry_MX_1.00u_PCB
SW260: V; SW_Cherry_MX_1.00u_PCB
SW261: B; SW_Cherry_MX_1.00u_PCB
SW262: N; SW_Cherry_MX_1.00u_PCB
SW263: M; SW_Cherry_MX_1.00u_PCB
SW264: COMMA; SW_Cherry_MX_1.00u_PCB
SW265: PERIOD; SW_Cherry_MX_1.00u_PCB
SW266: SLASH; SW_Cherry_MX_1.00u_PCB
SW267: RSHIFT; SW_Cherry_MX_1.75u_PCB
SW268: INV; SW_Cherry_MX_1.00u_PCB
SW269: BREAK; SW_Cherry_MX_1.00u_PCB
SW270: SPACE; SW_Cherry_MX_6.25u_PCB

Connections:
C1: SW201.2 (B), SW210.2 (B), SW219.2 (B), SW228.2 (B), SW237.2 (B), SW246.2 (B), SW255.2 (B); also elsewhere on the board
C2: SW202.2 (B), SW211.2 (B), SW220.2 (B), SW229.2 (B), SW238.2 (B), SW247.2 (B), SW256.2 (B); also elsewhere on the board
C3: SW203.2 (B), SW212.2 (B), SW221.2 (B), SW230.2 (B), SW239.2 (B), SW248.2 (B), SW257.2 (B); also elsewhere on the board
C4: SW204.2 (B), SW213.2 (B), SW222.2 (B), SW231.2 (B), SW240.2 (B), SW249.2 (B), SW258.2 (B); also elsewhere on the board
C5: SW205.2 (B), SW214.2 (B), SW223.2 (B), SW232.2 (B), SW241.2 (B), SW250.2 (B), SW259.2 (B); also elsewhere on the board
C6: SW206.2 (B), SW215.2 (B), SW224.2 (B), SW233.2 (B), SW242.2 (B), SW251.2 (B), SW260.2 (B), SW264.2 (B), SW268.2 (B); also elsewhere on the board
C7: SW207.2 (B), SW216.2 (B), SW225.2 (B), SW234.2 (B), SW243.2 (B), SW252.2 (B), SW261.2 (B), SW265.2 (B), SW269.2 (B); also elsewhere on the board
C8: SW208.2 (B), SW217.2 (B), SW226.2 (B), SW235.2 (B), SW244.2 (B), SW253.2 (B), SW262.2 (B), SW266.2 (B), SW270.2 (B); also elsewhere on the board
C9: SW209.2 (B), SW218.2 (B), SW227.2 (B), SW236.2 (B), SW245.2 (B), SW254.2 (B), SW263.2 (B), SW267.2 (B); also elsewhere on the board
unnamed: D201.2 (A), SW201.1 (A)
unnamed: D202.2 (A), SW202.1 (A)
unnamed: D203.2 (A), SW203.1 (A)
unnamed: D204.2 (A), SW204.1 (A)
unnamed: D205.2 (A), SW205.1 (A)
unnamed: D206.2 (A), SW206.1 (A)
unnamed: D207.2 (A), SW207.1 (A)
unnamed: D208.2 (A), SW208.1 (A)
unnamed: D209.2 (A), SW209.1 (A)
unnamed: D210.2 (A), SW210.1 (A)
unnamed: D211.2 (A), SW211.1 (A)
unnamed: D212.2 (A), SW212.1 (A)
unnamed: D213.2 (A), SW213.1 (A)
unnamed: D214.2 (A), SW214.1 (A)
unnamed: D215.2 (A), SW215.1 (A)
unnamed: D216.2 (A), SW216.1 (A)
unnamed: D217.2 (A), SW217.1 (A)
unnamed: D218.2 (A), SW218.1 (A)
unnamed: D219.2 (A), SW219.1 (A)
unnamed: D220.2 (A), SW220.1 (A)
unnamed: D221.2 (A), SW221.1 (A)
unnamed: D222.2 (A), SW222.1 (A)
unnamed: D223.2 (A), SW223.1 (A)
unnamed: D224.2 (A), SW224.1 (A)
unnamed: D225.2 (A), SW225.1 (A)
unnamed: D226.2 (A), SW226.1 (A)
unnamed: D227.2 (A), SW227.1 (A)
unnamed: D228.2 (A), SW228.1 (A)
unnamed: D229.2 (A), SW229.1 (A)
unnamed: D230.2 (A), SW230.1 (A)
unnamed: D231.2 (A), SW231.1 (A)
unnamed: D232.2 (A), SW232.1 (A)
unnamed: D233.2 (A), SW233.1 (A)
unnamed: D234.2 (A), SW234.1 (A)
unnamed: D235.2 (A), SW235.1 (A)
unnamed: D236.2 (A), SW236.1 (A)
unnamed: D237.2 (A), SW237.1 (A)
unnamed: D238.2 (A), SW238.1 (A)
unnamed: D239.2 (A), SW239.1 (A)
unnamed: D240.2 (A), SW240.1 (A)
unnamed: D241.2 (A), SW241.1 (A)
unnamed: D242.2 (A), SW242.1 (A)
unnamed: D243.2 (A), SW243.1 (A)
unnamed: D244.2 (A), SW244.1 (A)
unnamed: D245.2 (A), SW245.1 (A)
unnamed: D246.2 (A), SW246.1 (A)
unnamed: D247.2 (A), SW247.1 (A)
unnamed: D248.2 (A), SW248.1 (A)
unnamed: D249.2 (A), SW249.1 (A)
unnamed: D250.2 (A), SW250.1 (A)
unnamed: D251.2 (A), SW251.1 (A)
unnamed: D252.2 (A), SW252.1 (A)
unnamed: D253.2 (A), SW253.1 (A)
unnamed: D254.2 (A), SW254.1 (A)
unnamed: D255.2 (A), SW255.1 (A)
unnamed: D256.2 (A), SW256.1 (A)
unnamed: D257.2 (A), SW257.1 (A)
unnamed: D258.2 (A), SW258.1 (A)
unnamed: D259.2 (A), SW259.1 (A)
unnamed: D260.2 (A), SW260.1 (A)
unnamed: D261.2 (A), SW261.1 (A)
unnamed: D262.2 (A), SW262.1 (A)
unnamed: D263.2 (A), SW263.1 (A)
unnamed: D264.2 (A), SW264.1 (A)
unnamed: D265.2 (A), SW265.1 (A)
unnamed: D266.2 (A), SW266.1 (A)
unnamed: D267.2 (A), SW267.1 (A)
unnamed: D268.2 (A), SW268.1 (A)
unnamed: D269.2 (A), SW269.1 (A)
unnamed: D270.2 (A), SW270.1 (A)
R1: D201.1 (K), D202.1 (K), D203.1 (K), D204.1 (K), D205.1 (K), D206.1 (K), D207.1 (K), D208.1 (K), D209.1 (K); also elsewhere on the board
R2: D210.1 (K), D211.1 (K), D212.1 (K), D213.1 (K), D214.1 (K), D215.1 (K), D216.1 (K), D217.1 (K), D218.1 (K); also elsewhere on the board
R3: D219.1 (K), D220.1 (K), D221.1 (K), D222.1 (K), D223.1 (K), D224.1 (K), D225.1 (K), D226.1 (K), D227.1 (K); also elsewhere on the board
R4: D228.1 (K), D229.1 (K), D230.1 (K), D231.1 (K), D232.1 (K), D233.1 (K), D234.1 (K), D235.1 (K), D236.1 (K); also elsewhere on the board
R5: D237.1 (K), D238.1 (K), D239.1 (K), D240.1 (K), D241.1 (K), D242.1 (K), D243.1 (K), D244.1 (K), D245.1 (K); also elsewhere on the board
R6: D246.1 (K), D247.1 (K), D248.1 (K), D249.1 (K), D250.1 (K), D251.1 (K), D252.1 (K), D253.1 (K), D254.1 (K); also elsewhere on the board
R7: D255.1 (K), D256.1 (K), D257.1 (K), D258.1 (K), D259.1 (K), D260.1 (K), D261.1 (K), D262.1 (K), D263.1 (K); also elsewhere on the board
R8: D264.1 (K), D265.1 (K), D266.1 (K), D267.1 (K); also elsewhere on the board
R9: D268.1 (K), D269.1 (K), D270.1 (K); also elsewhere on the board

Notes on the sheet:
RESERVED FOR JOYSTICK INPUTS

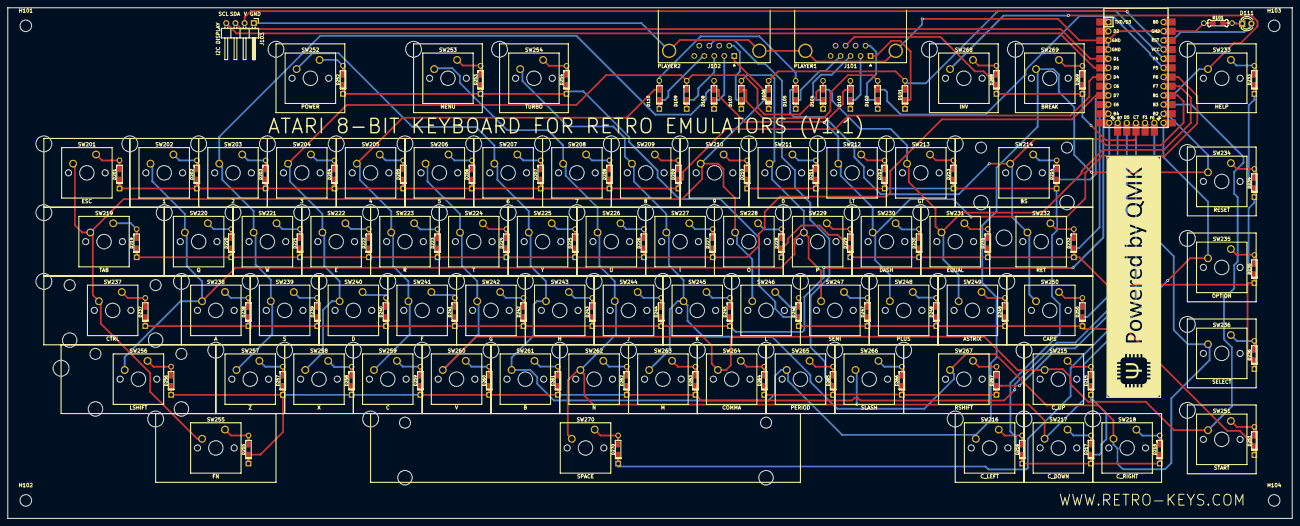
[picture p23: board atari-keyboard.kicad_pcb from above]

Board: 2 copper layers, 355.8 x 141.4 mm, 160 parts (0 on the bottom side), 103 nets.

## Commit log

2022-12-25 Added keycap generator
    [3d_surface.scad, 4x6.scad, 4x6_legends.scad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]
2022-12-25 Added kicad-lib
    [asm_mx_asm_PCB.stp, asm_mx_asm_PLATE.stp]
2022-12-25 Added Atari-A8 PCB
    [atari-keyboard.kicad_sch, atari-keyboard.sch, keyboard.kicad_sch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]
2022-12-26 More cleanup of the PCB traces.
    [router.dsn]
2022-12-26 Added SOD-123 diode models to PCB
    [SOD-123.step, SOD-323.step, SOD-523.step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]
2022-12-26 Replaced unix command line tools to convert stl to wrl with a python script.
2022-12-26 Cleaned up some more trace.
    [atari-keyboard.kicad_pcb]
2022-12-26 No longer need standoff holes as part of the schematic. Added automatically by the script.
2022-12-26 Used new standoff holes and more track cleanup work.
    [atari-keyboard.kicad_pcb, atari-keyboard.kicad_sch, keyboard.kicad_sch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]
2022-12-26 Moved KeyV2 to be used commonly
    [3d_surface.scad, 4x6.scad, 4x6_legends.scad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]
2022-12-26 Created some keycaps just to generate web page legends with
    [atarikeys.scad, key_desc.scad, key_include.scad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]
2023-01-07 More rework of designing a printable key layout
    [atarikeys.scad, key_desc.scad, key_include.scad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]
2023-01-08 Started to work on case design
    [utils.scad]
2023-01-08 Fixed some autolayout for resin prints.
    [atarikeys.scad, key_include.scad, one_atari_key.scad]
2023-01-08 More work on case design done.
    [utils.scad]
2023-01-08 Fixed some standoff spacing
    Added labels to the bounding boxes and noticed that the manually
    positioned standoffs were in the wrong y location. Fixed that.
    [utils.scad]
2023-01-08 Cleaned up case design quite a bit
    [utils.scad]
2023-01-09 Moved the last hard-coded SCAD module out of the py file
    and increased the text of bounding boxes by limiting it to
    just the first two lettes..
    [utils.scad]
2023-01-12 Added the ability to slice the case into smaller pieces.
    [625u.stl, OctopusThickLegs.stl, bezier.scad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]
2023-01-14 Added countersunk case holes
    [utils.scad]
2023-01-23 Added code to auto-generate the keyboard and split it properly.
    [case-position.scad, utils.scad]
2023-01-23 Added a two-part case as well.
    [utils.scad]
